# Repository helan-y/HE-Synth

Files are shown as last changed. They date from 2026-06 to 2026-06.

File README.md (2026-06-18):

# HE Synth

## About
A custom, compact, modular velocity-sensitive digital synthesizer, made with Hall-Effect keyswitches and DaisySeed. 

## Idea
I want to make music and I do not have money but I do have blood, sweat, and many, many tears. This is also a proof of concept towards bigger projects I want to make in the future!
- MIDI keyboard with trackballs for keys! like a roli seaboard but weird and isomorphic! what if piano could vibrato!!
- bigger modular midi (repeating pcb boards in series one for each octave) keyboard with keycaps like piano keys!
- sampler! vocoder! etc!

## Features
Hardware features:
- Velocity-sensitive! Aftertouch! Two/three/more octaves!
- Fully **modular**. Add more octaves, swap out MIDI controllers, swap out the synthesizer. Assembled with separate custom PCB boards for maximum customizability. 
- In-build audio! 3.5 mm headphone jack or speaker. 

Constantly updating firmware:
- Different presets! Different sound envelopes!
- There's even a looper!
- And a display!

## PCB
The PCB design is divided into four parts:
1. Main Board
2. Power Distribution Board (PDB)
3. Octave PCBs
    - 12 Hall-Effect Keyswitches
    - STM32 MCU Chip
    - UART data transmission
4. MIDI-Out PCB
    - ESP32
    - MIDI OUT
    - USB-C

### Main Board
- Contains the Daisy Seed
- Switches, rotary encoders, and potentiometers
- Display with microSD card
- Ports!
    - MIDI IN
    - AUDIO IN x2
    - AUDIO OUT x2
    - 3.5mm Headphone Jack
    - microUSB for programming the Daisy
    - USB-C for data

### PDB
- USB-C charging
- Battery management
- 6000 mAh Li-Po
- Boost to 5V
- Buck-Boost to 3V3

### Octave PCB
An octave of velocity-sensitive keys. Hall-effect sensors, processed into usable data for the Daisy Seed. 
- 12 Hall-Effect Keyswitches
- STM32 MCU Chip
- UART data transmission

### MIDI-Out PCB
- ESP32
- MIDI OUT
- USB-C

## CAD

## Firmware
Firmware coded with C++ and libraries libDaisy and daisySP. 

## BOM
### Main PCB
- 1x Electro-Smith Daisy Seed
- 2x EC11 Rotary Encoders
- 6x Cherry MX Keyswitches
- 9x Potentiometers
- 1x 3-pin Male Header JST-PH
- 1x 10-pin JST
- 1x 4-pin Male Header JST-PH
- 2x DIN-5 MIDI Jack
- 1x 3.5mm Headphone Jack
- 2x PJ-320 Jacks
- 1x Optocoupler
- 1x Speaker

### Octave PCB 
- 12x Gateron Jade Magnetic Switches
- 12x Linear Hall-Effect Sensors
- 1x STM32
- 12x 0.1uF Capacitors
- 1x 2-Pin Male Header JST-PH 
- 1x 4-Pin Male Header JST-PH
- 1x RS-485
- 1x 3-Bit DIP Switch

Three of these for this particular iteration!

### Power Distribution Board
- 1x USB-C Receptacle
- 3x 2-Pin Male Header JST-PH
- 1x 3-Pin Male Header JST-PH
-

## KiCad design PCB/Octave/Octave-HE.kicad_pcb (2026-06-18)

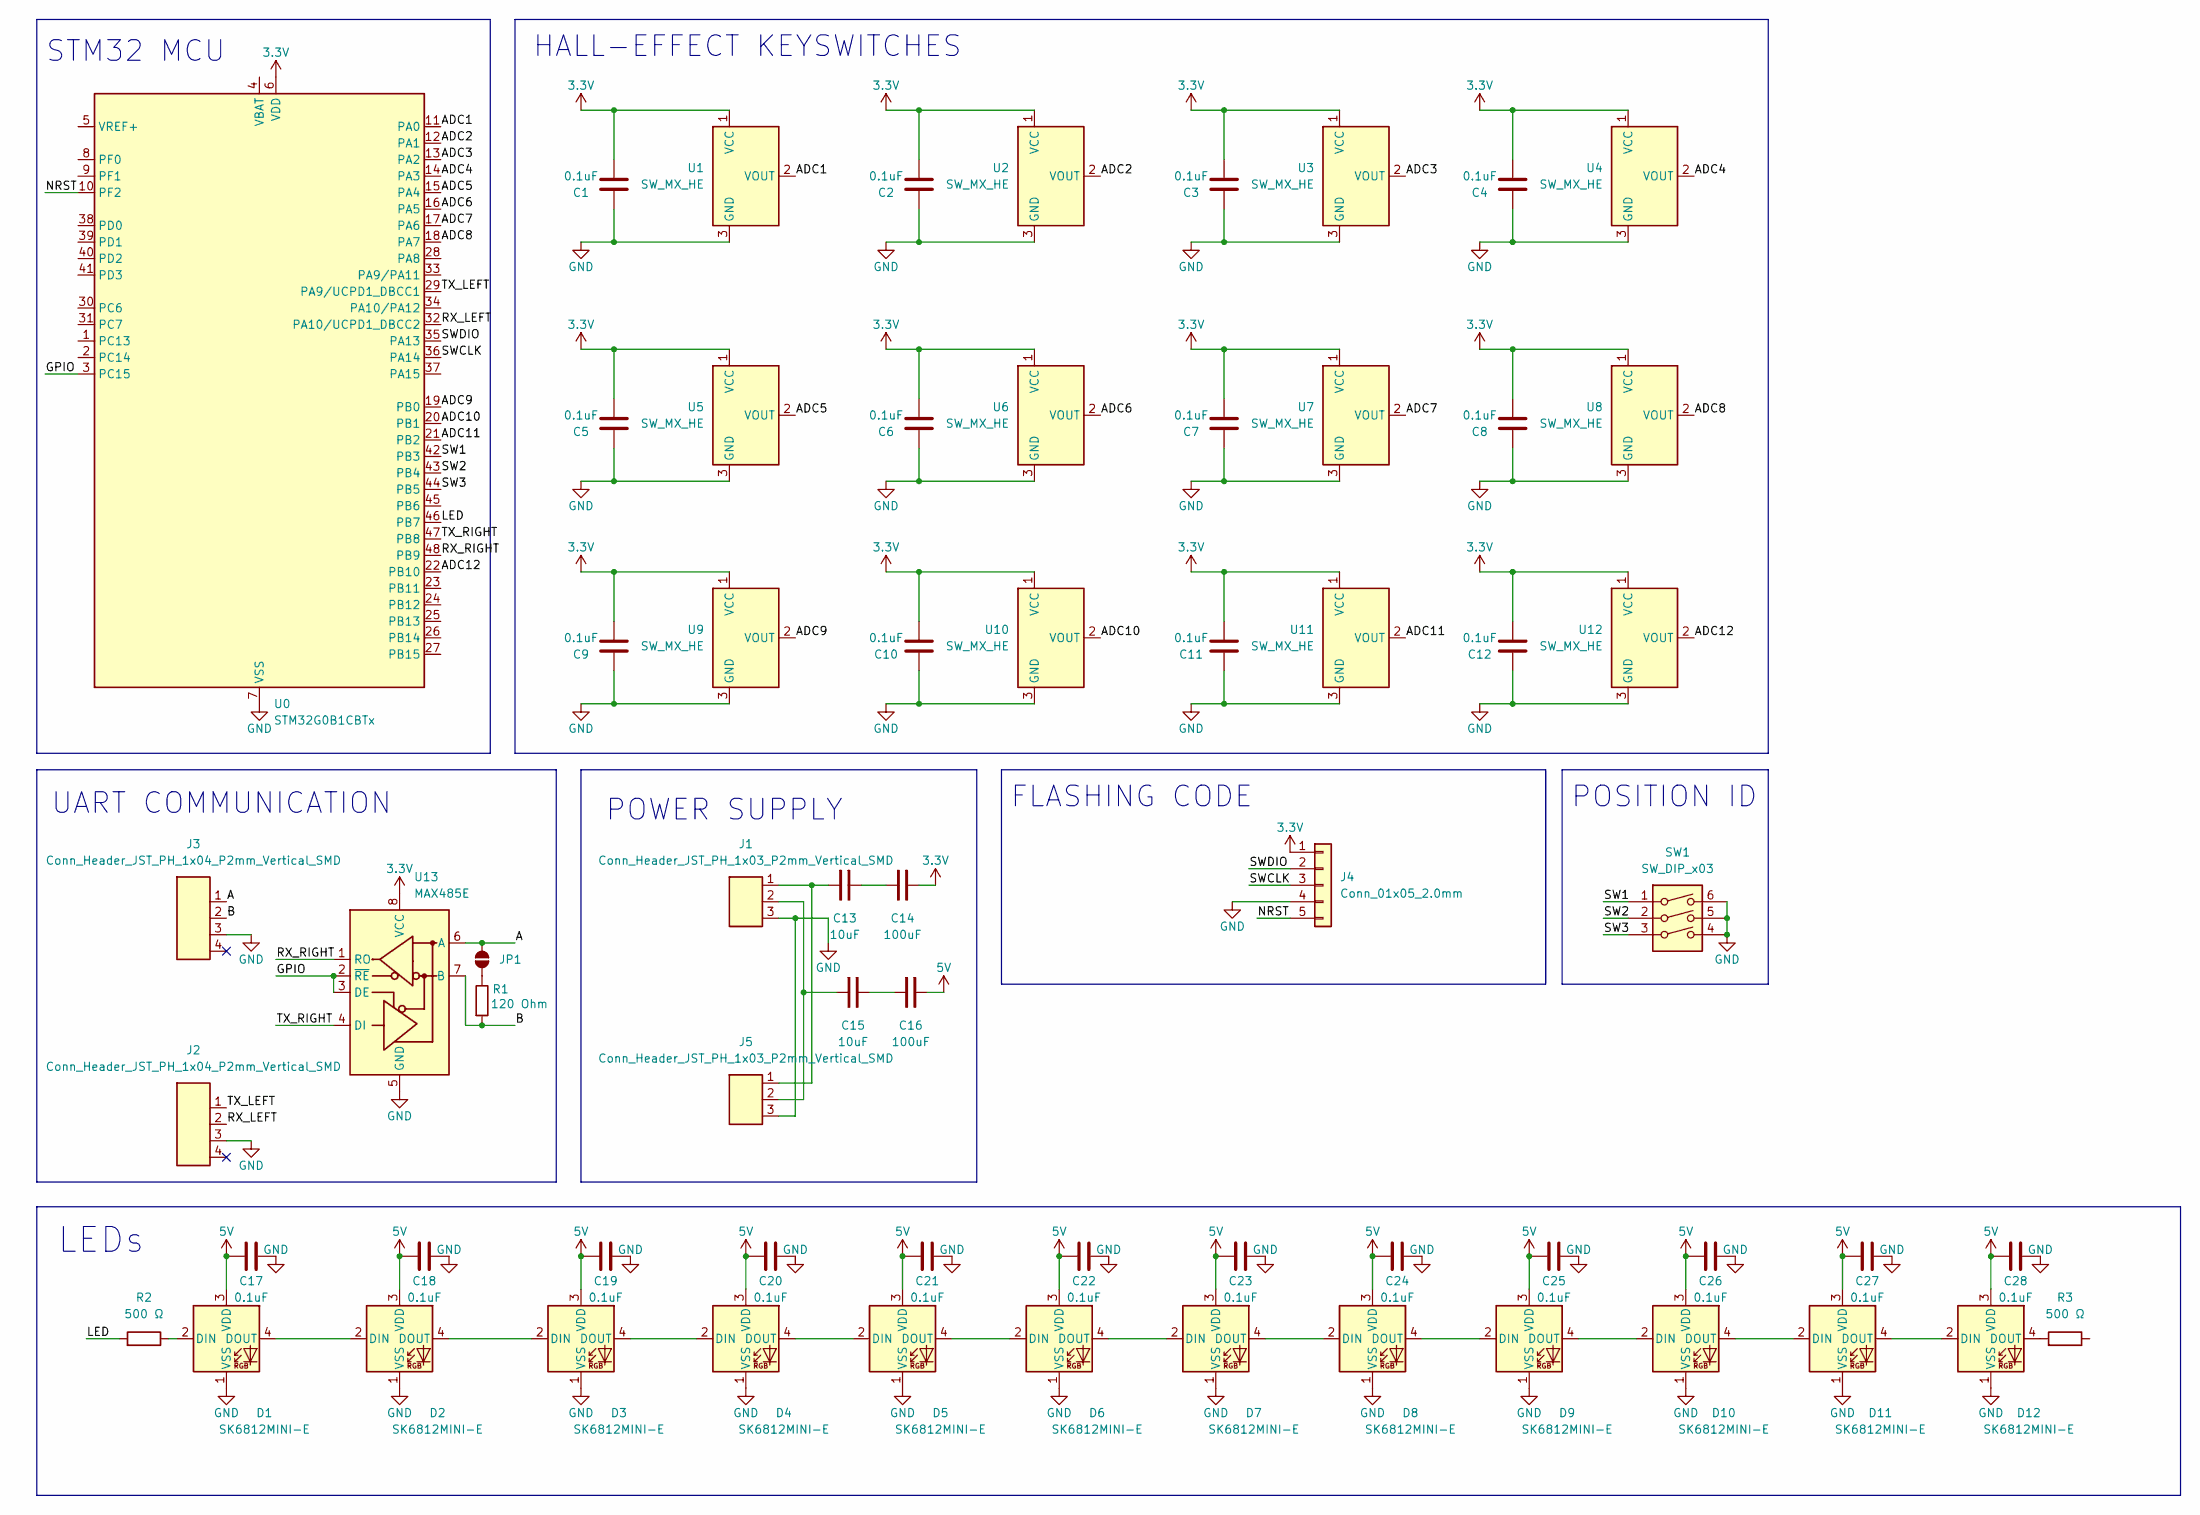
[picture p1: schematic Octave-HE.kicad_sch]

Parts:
C1, C2, C3, C4, C5, C6, C7, C8, C9, C10, C11, C12, C17, C18, C19, C20, C21, C22, C23, C24, C25, C26, C27, C28: 0.1uF; C_0201_0603Metric_Clearance
C13, C15: 10uF; CP_EIA-3216-10_Kemet-I_HandSolder
C14, C16: 100uF; CP_EIA-3216-10_Kemet-I_HandSolder
D1, D2, D3, D4, D5, D6, D7, D8, D9, D10, D11, D12: SK6812MINI-E; LED_SK6812MINI-E_3.2x2.8mm_P1.5mm_ReverseMount_clearance
J1, J5: Conn_Header_JST_PH_1x03_P2mm_Vertical_SMD; Header_JST_PH_1x03_P2mm_Vertical_SMD
J2, J3: Conn_Header_JST_PH_1x04_P2mm_Vertical_SMD; Header_JST_PH_1x04_P2mm_Vertical_SMD
J4: Conn_01x05_2.0mm; 1x05_P2.0mm_Socket_Vertical_SMD_Pin1RightDown
JP1: Jumper_2_NO
R1: 120 Ohm; R_0201_0603Metric
R2, R3: 500 Ω; R_0402_1005Metric
SW1: SW_DIP_x03; SW_DIP_SPSTx03_Slide_6.7x9.18mm_W6.73mm_P2.54mm_LowProfile_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
U0: STM32G0B1CBTx; LQFP-48_7x7mm_P0.5mm
U1, U2, U3, U4, U5, U6, U7, U8, U9, U10, U11, U12: SW_MX_HE; SW_MX_HE_0deg_1u
U13: MAX485E; SOIC-8_3.9x4.9mm_P1.27mm

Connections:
3.3V: C1.2, C2.2, C3.2, C4.2, C5.2, C6.2, C7.2, C8.2, C9.2, C10.2, C11.2, C12.2, C14.2, J4.1, U0.6 (VDD), U1.1 (VCC), U2.1 (VCC), U3.1 (VCC), U4.1 (VCC), U5.1 (VCC), U6.1 (VCC), U7.1 (VCC), U8.1 (VCC), U9.1 (VCC), U10.1 (VCC), U11.1 (VCC), U12.1 (VCC), U13.8 (VCC)
5V: C16.2, C17.2, C18.2, C19.2, C20.2, C21.2, C22.2, C23.2, C24.2, C25.2, C26.2, C27.2, C28.2, D1.3 (VDD), D2.3 (VDD), D3.3 (VDD), D4.3 (VDD), D5.3 (VDD), D6.3 (VDD), D7.3 (VDD), D8.3 (VDD), D9.3 (VDD), D10.3 (VDD), D11.3 (VDD), D12.3 (VDD)
/A: J3.1, JP1.2 (B), U13.6 (A)
/ADC1: U0.11 (PA0), U1.2 (VOUT)
/ADC2: U0.12 (PA1), U2.2 (VOUT)
/ADC3: U0.13 (PA2), U3.2 (VOUT)
/ADC4: U0.14 (PA3), U4.2 (VOUT)
/ADC5: U0.15 (PA4), U5.2 (VOUT)
/ADC6: U0.16 (PA5), U6.2 (VOUT)
/ADC7: U0.17 (PA6), U7.2 (VOUT)
/ADC8: U0.18 (PA7), U8.2 (VOUT)
/ADC9: U0.19 (PB0), U9.2 (VOUT)
/ADC10: U0.20 (PB1), U10.2 (VOUT)
/ADC11: U0.21 (PB2), U11.2 (VOUT)
/ADC12: U0.22 (PB10), U12.2 (VOUT)
/B: J3.2, R1.1, U13.7 (B)
/GPIO: U0.3 (PC15), U13.2 (~RE), U13.3 (DE)
/LED: R2.1, U0.46 (PB7)
/NRST: J4.5, U0.10 (PF2)
/RX_LEFT: J2.2, U0.32 (PA10/UCPD1_DBCC2)
/RX_RIGHT: U0.48 (PB9), U13.1 (RO)
/SW1: SW1.1, U0.42 (PB3)
/SW2: SW1.2, U0.43 (PB4)
/SW3: SW1.3, U0.44 (PB5)
/SWCLK: J4.3, U0.36 (PA14)
/SWDIO: J4.2, U0.35 (PA13)
/TX_LEFT: J2.1, U0.29 (PA9/UCPD1_DBCC1)
/TX_RIGHT: U0.47 (PB8), U13.4 (DI)
GND: C1.1, C2.1, C3.1, C4.1, C5.1, C6.1, C7.1, C8.1, C9.1, C10.1, C11.1, C12.1, C17.1, C18.1, C19.1, C20.1, C21.1, C22.1, C23.1, C24.1, C25.1, C26.1, C27.1, C28.1, D1.1 (VSS), D2.1 (VSS), D3.1 (VSS), D4.1 (VSS), D5.1 (VSS), D6.1 (VSS), D7.1 (VSS), D8.1 (VSS), D9.1 (VSS), D10.1 (VSS), D11.1 (VSS), D12.1 (VSS), J1.3, J2.3, J3.3, J4.4, J5.3, SW1.4, SW1.5, SW1.6, U0.7 (VSS), U1.3 (GND), U2.3 (GND), U3.3 (GND), U4.3 (GND), U5.3 (GND), U6.3 (GND), U7.3 (GND), U8.3 (GND), U9.3 (GND), U10.3 (GND), U11.3 (GND), U12.3 (GND), U13.5 (GND)
unnamed: C13.1, J1.1, J5.1
unnamed: C13.2, C14.1
unnamed: C15.1, J1.2, J5.2
unnamed: C15.2, C16.1
unnamed: D1.2 (DIN), R2.2
unnamed: D1.4 (DOUT), D2.2 (DIN)
unnamed: D2.4 (DOUT), D3.2 (DIN)
unnamed: D3.4 (DOUT), D4.2 (DIN)
unnamed: D4.4 (DOUT), D5.2 (DIN)
unnamed: D5.4 (DOUT), D6.2 (DIN)
unnamed: D6.4 (DOUT), D7.2 (DIN)
unnamed: D7.4 (DOUT), D8.2 (DIN)
unnamed: D8.4 (DOUT), D9.2 (DIN)
unnamed: D9.4 (DOUT), D10.2 (DIN)
unnamed: D10.4 (DOUT), D11.2 (DIN)
unnamed: D11.4 (DOUT), D12.2 (DIN)
unnamed: D12.4 (DOUT), R3.1
unnamed: JP1.1 (A), R1.2

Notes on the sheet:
HALL-EFFECT KEYSWITCHES
LEDs
POSITION ID
STM32 MCU
UART COMMUNICATION
FLASHING CODE
POWER SUPPLY

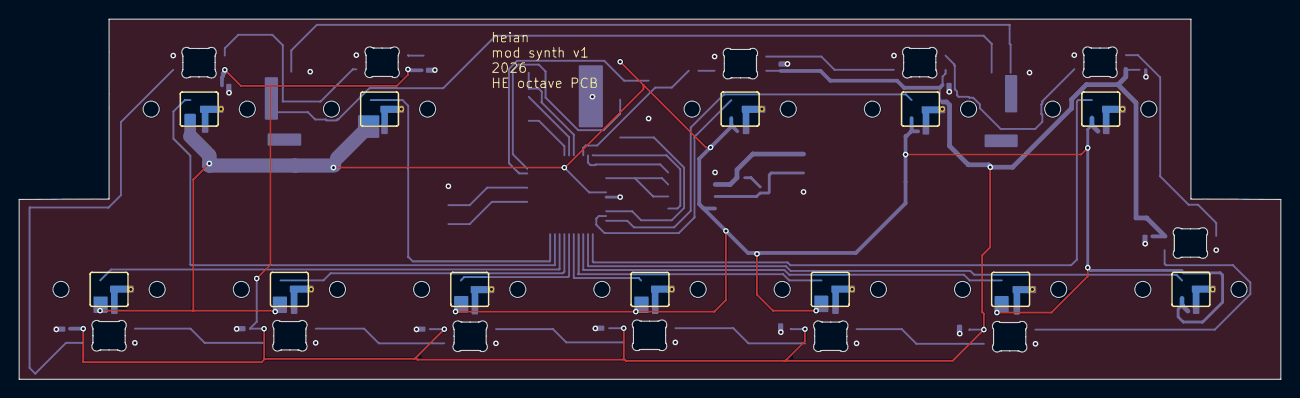
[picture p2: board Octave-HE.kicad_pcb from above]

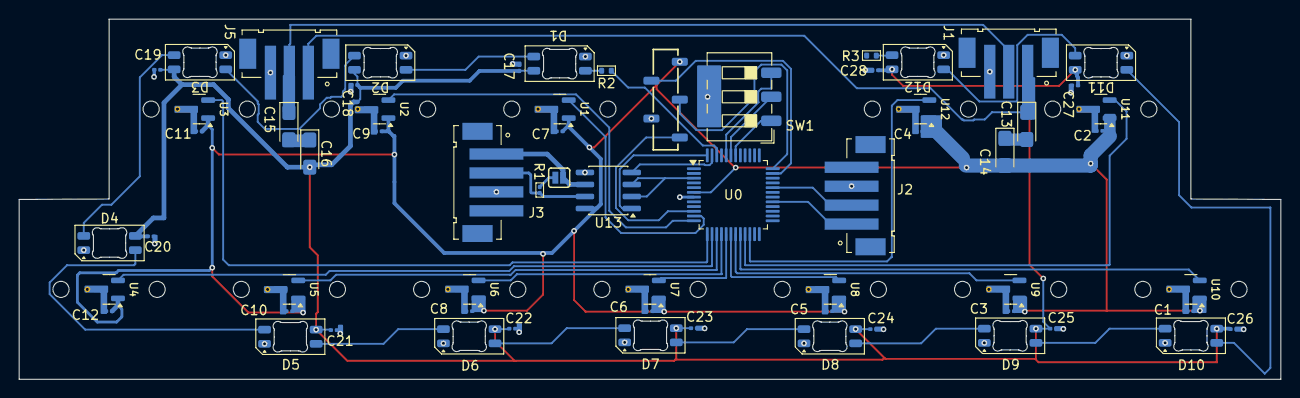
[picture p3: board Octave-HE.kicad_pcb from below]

Board: 2 copper layers, 133.3 x 38.0 mm, 64 parts (64 on the bottom side), 47 nets.

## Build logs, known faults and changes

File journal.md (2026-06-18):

# journal #1: research, planning & starting on the schematic

this is going to be so long because this is planning for the whole project. this has been bouncing around my brain for a while so uh here. 

i want a compact synth! i am mildly broke and synths are expensive! i am fully willing to invest blood, sweat, and tears!

So much time off-camera spent on research and hunting down parts. This was a shockingly massive undertaking. I really should have learned signals & systems before doing this. Or maybe taken apart an existing synth. Or maybe tried something smaller. Oh well!

features (hopefully):
- - Velocity-sensitive!
- Two/three/more octaves!
- In-build audio! 3.5 mm headphone jack or speaker. 
- Different presets! Different sound envelopes!
- There's even a looper!
- And a display!

Five main problems for the schematic:
- Not enough pins. 24 hall-effect keys all need ADC (analog to digital) pins. 6 rotary encoders. A display. Some pins also have specialized functions, so not all pins are interchangeable. 
- Different demands on power supply. Linear hall-effect sensors run on 3V3. Sound systems generally run on 5V. LiPo Batteries supply 3.7V - 4.2V. The daisy seed can supply 3V3 but I don't think it has enough to power all the systems that need it, and it definitely doesn't have 5V. 
- Enough power?? This might take a lot of power? 
- Hall-effect switches. Getting all of the specifications and all that jazz. Never worked with them before! Should be fun!
- Signal integrity & latency. This is probably my biggest concern. I don't care that much about polling rate, but I do need the synth to not have noticable lag. The solutions to "not enough pins" also tends to collide with this problem. And I need the data from the keys to be coherent by the time the daisy seed processes it. 

Tentative solutions:
- I first thought about using analog multiplexers, but those scan too slowly, and that would require the Daisy to process all Hall-Effect inputs, both which would probably introduce lag to the keyboard. 
- Second solution --> make it modular. This was a much better idea. 
    1. It's going to save a bit in cost! the main pcb board is probably going to be 4 layers just because I don't want to deal with muddled signals, but the keyboard PCBs don't have to be! You also have to order at least 5 PCBs in one batch so that works well with this.
    2. It's modular! You can add more octaves to the synth without having to rehaul the entire thing or design a new PCB!
    3. Saves on processing time! Probably reduces latency! Each octave board has an onboard MCU chip that processes sensor information and returns velocity. 
    4. Cleaner signals!

So the PCB design is going to be divided into three parts:
1. Main Board
    - Contains the Daisy Seed!
    - switches, rotary encoders, and potentiometers!
    - a display with microSD!
    - ports!
        - MIDI IN
        - MIDI OUT
        - AUDIO IN
        - AUDIO OUT
        - 3.5mm Headphone Jack
        - microUSB for programming the Daisy
2. Power Distribution Board (PDB)
    - USB-C charging
    - Battery management
    - Boost to 5V
    - Buck-Boost to 3V3
3. Octave PCBs
    - 12 Hall-Effect Keyswitches
    - STM32 MCU Chip
    - UART connected in series

for this session, i worked on assembling the main schematic and arranging the PCB. 

took shockingly long. finding a display and figuring out the pins? the one specific JST connectors where the pins were just a little off on the schematic, making it basically impossible to connect nets or wires?? finding all the 3d models?? i'm glad the planning is finally over though. this has been such a long project. 

i need to finish adding the ports and figuring out if i need a mux for all the inputs, but most the parts are here!!

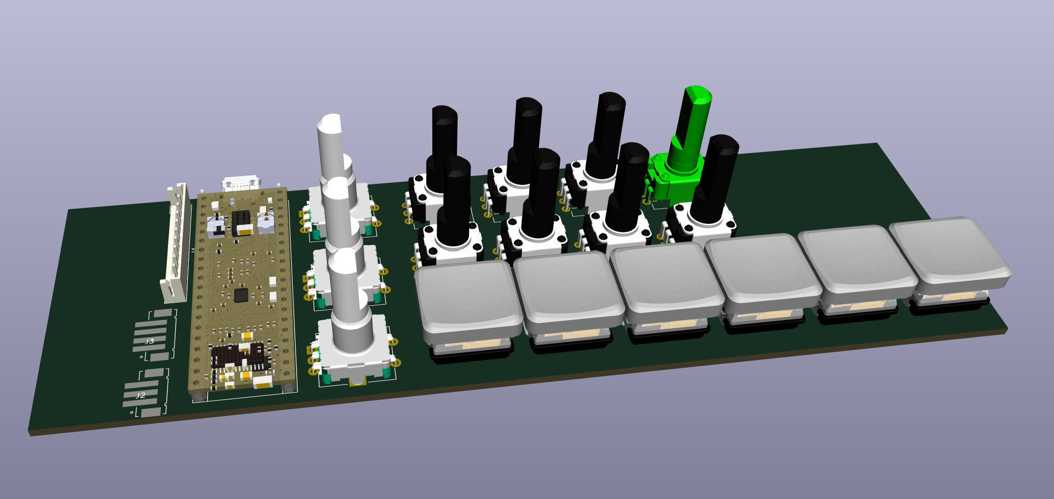
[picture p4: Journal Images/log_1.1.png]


# journal #2: octave PCB & research

so much research. my lord. 

so i'm planning for this synth to really be a modular midi keyboard + a daisy synthesizer. i should make one more PCB that's home to a microcontroller that processes the data from the octave PCBs and forwards it to the Main PCB (where the daisy is, or basically the synth). this way it's fully modular. if i want to swap out different midi keyboards or different synths i can quite easily. 

worked on the octave board! learned quite a lot about kicad and how to handle footprints and 3d models so hopefully my life should get easier later. found out i was editing specific footprints so the 3d models never saved :\( lesson learned !!

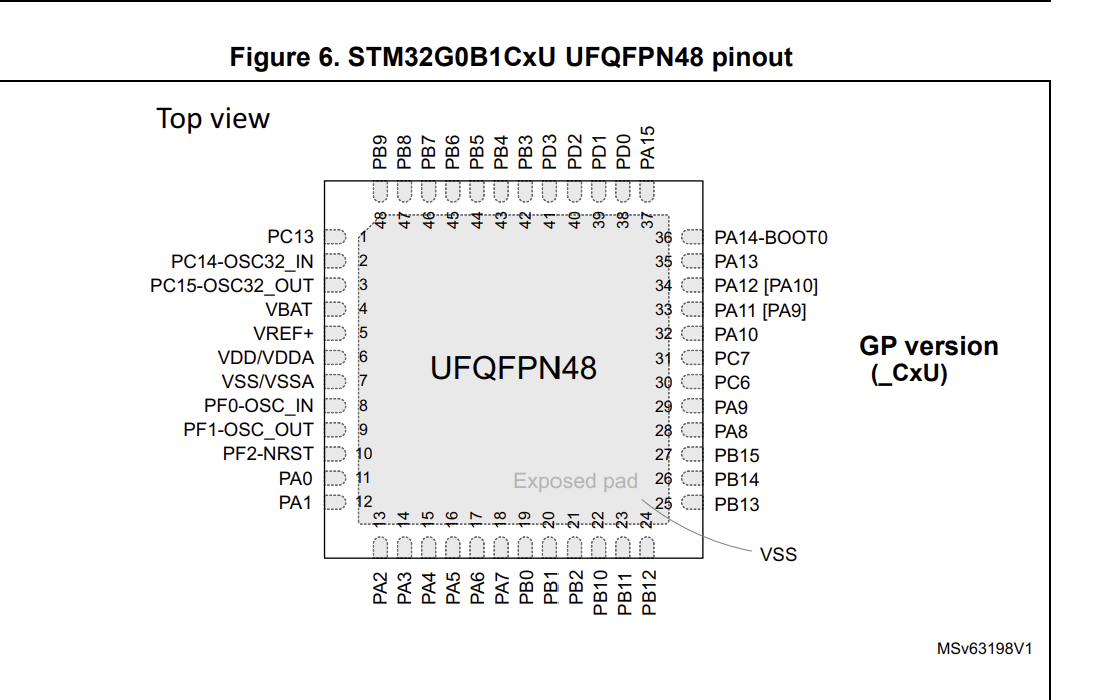
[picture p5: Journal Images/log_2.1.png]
)

have laid out the general schematic and pcb. i still need to figure out uart protocol and how to use the rs-485 to reduce interference. but that comes later

this was fairly simple ! at least this bit ! and i get a nice board to look at !

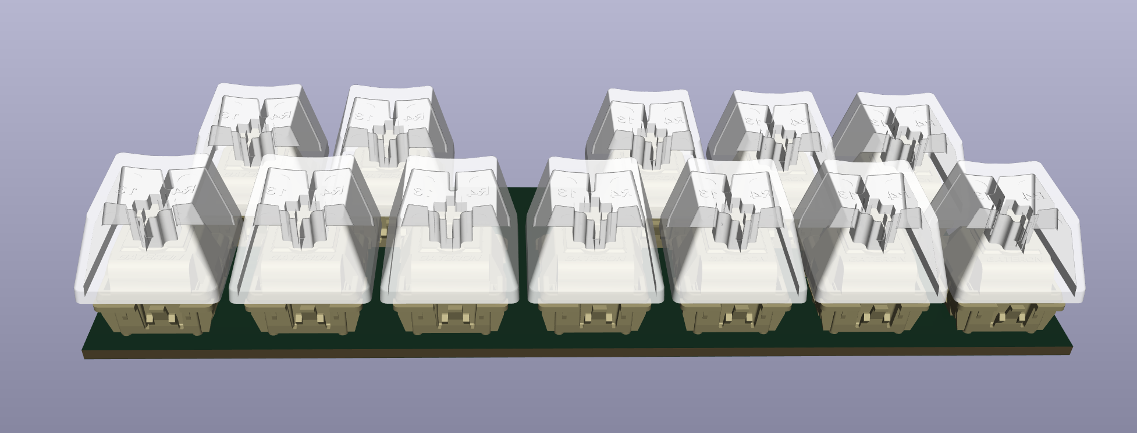
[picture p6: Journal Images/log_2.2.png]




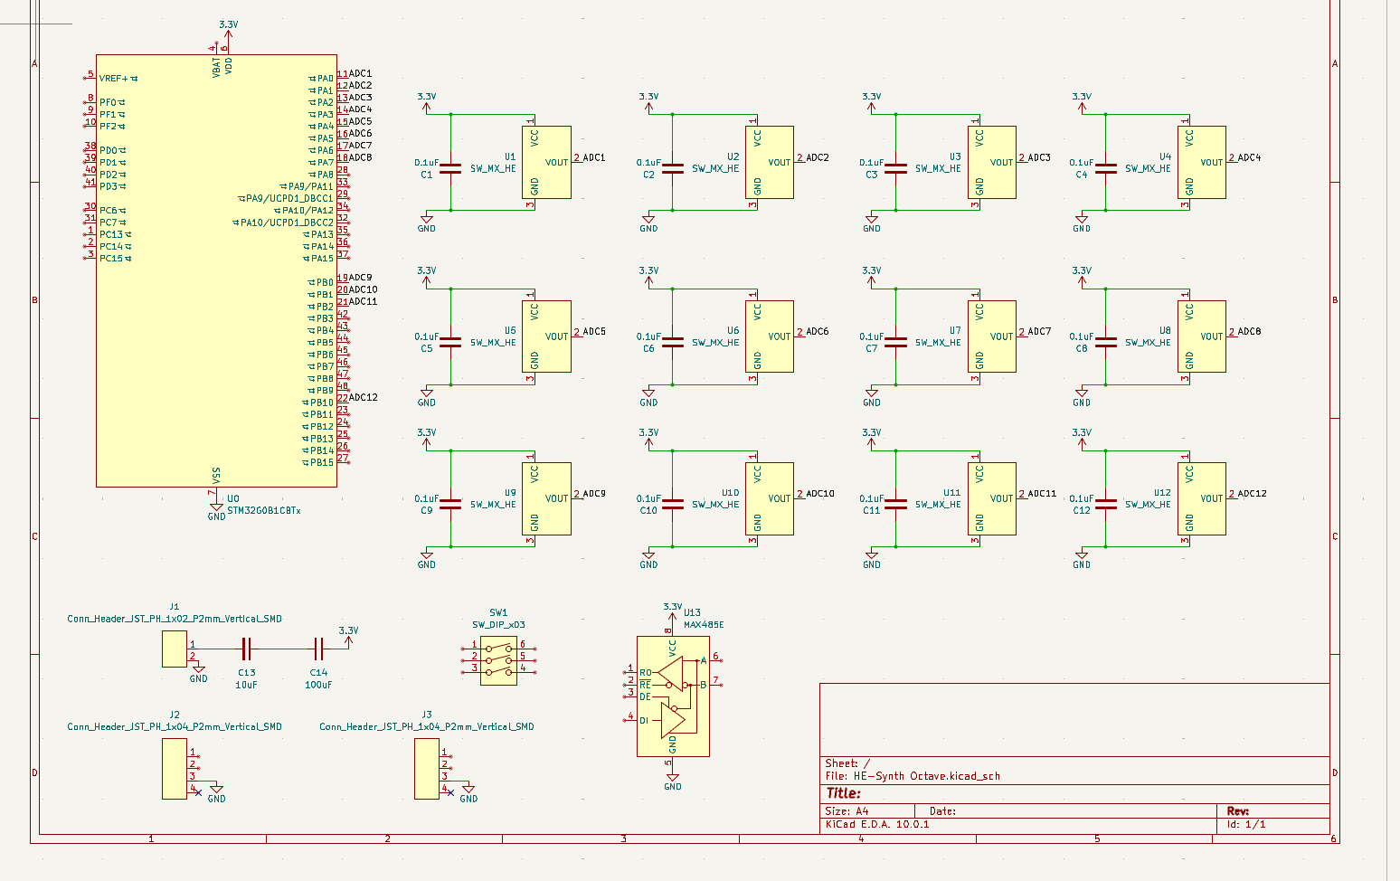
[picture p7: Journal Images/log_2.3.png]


# journal #3: octave PCB finished \(pain and suffering\) 

so this is unwireable. i either fix the schematic or swap the layout or this has to be a 4 layer board. four layer boards are so much more expensive.

i did not know that this would be the prelude to THREE HOURS of suffering. 

again engineering is the measure of how much you can tolerate small successive problems until you combust. 

## schematic

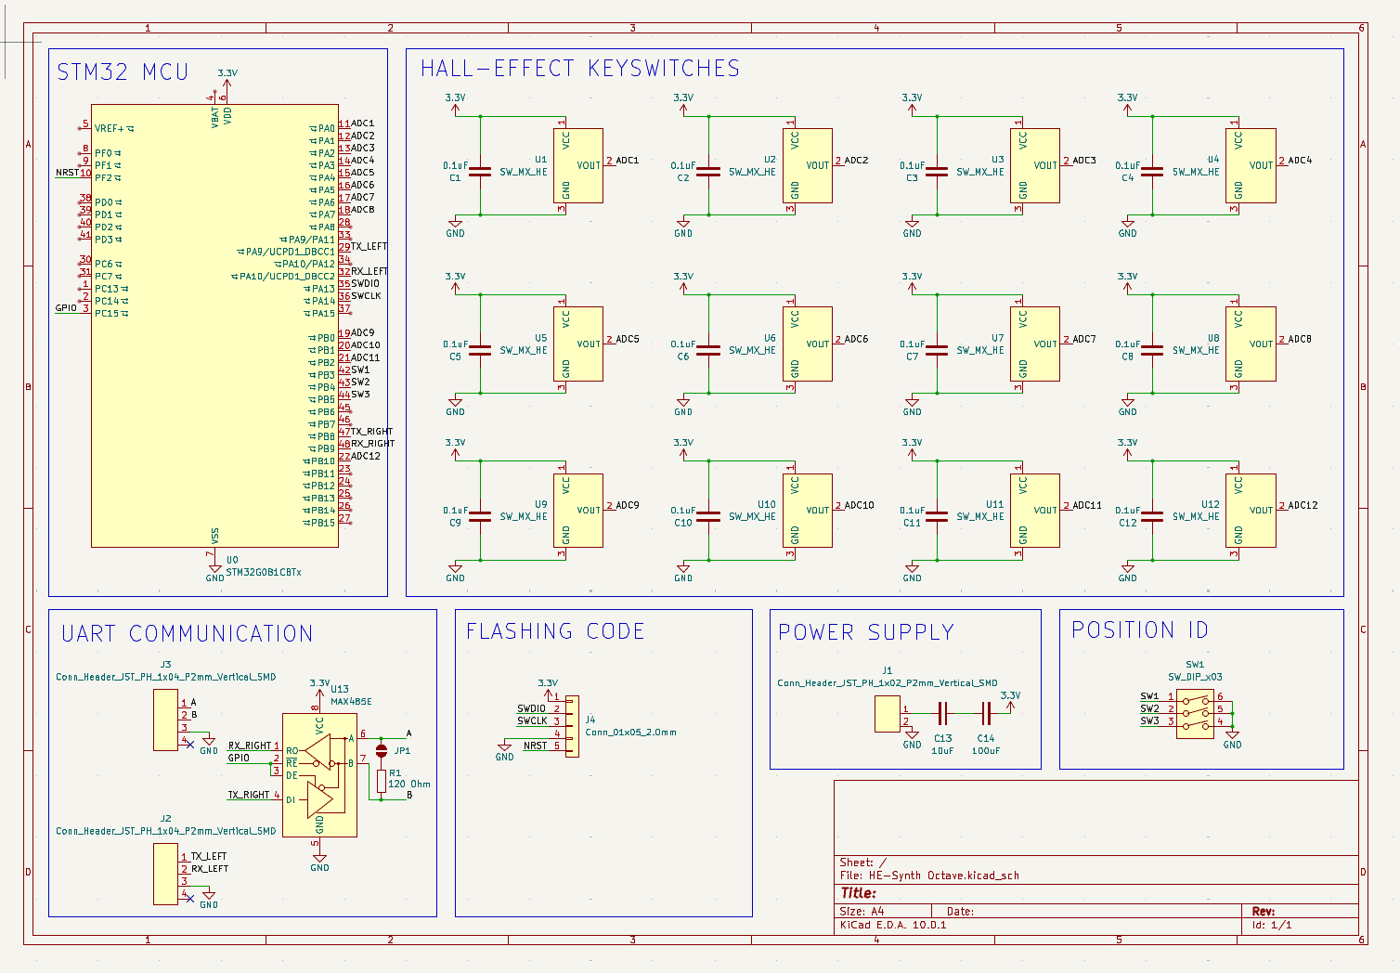
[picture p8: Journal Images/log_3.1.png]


this was mostly just staring at the datasheet and then the pcb to figure out which pins were available for which function, then which pin i COULD use that wouldn't ruin my life for wiring. this sounds so simple but it probably ate an hour just trying to figure out which configurations would work. thankfully i'm a bit more familiar with STM32 now, so future projects should go a little smoother.

## PCB

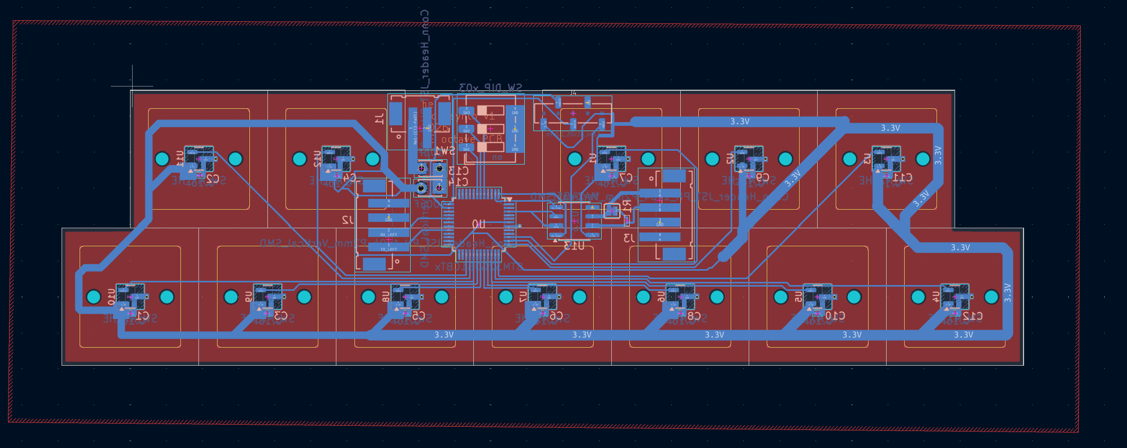
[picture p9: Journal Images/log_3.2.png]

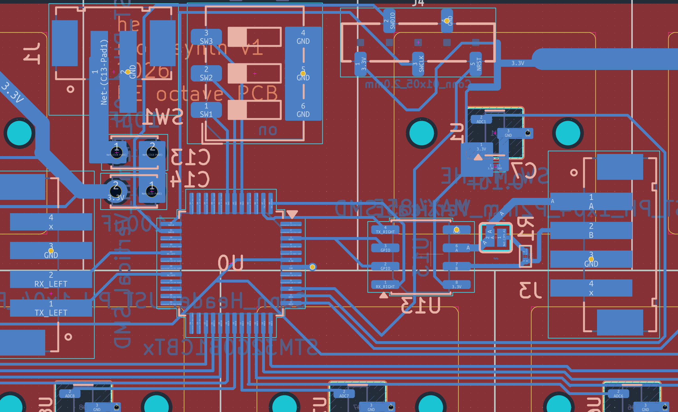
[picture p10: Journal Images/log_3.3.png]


wiring this was genuinely a nightmare. one layer is reserved for the GND plane for better signal processing, so no using two layers or vias to wire. i had to shuffle around so many of the keys just to be able to wire them to the correct adc pins. plus they can't interfere with the uart OR the power OR the firmware flashing port. had to move around so many part for this to function.

## PSB render

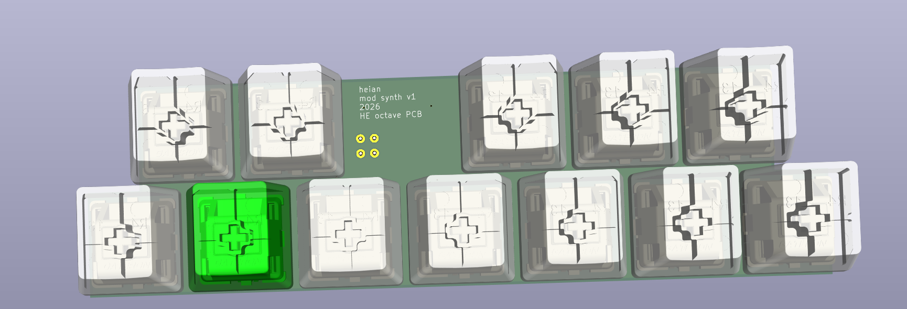
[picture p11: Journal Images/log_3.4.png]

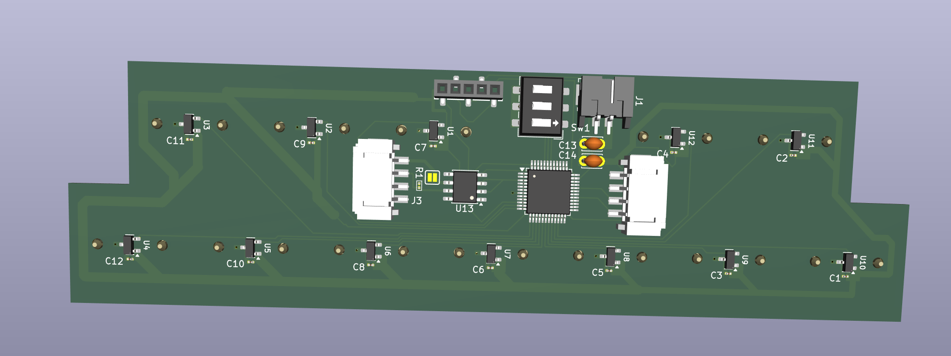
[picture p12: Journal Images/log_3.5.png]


I'M FREEEEE

# journal #4: laying out the main PCB

(extra hour for off lapse work) 

honestly a lot of just wrangling the layout and figuring out where the plugs are supposed to go?? and mapping out the regions of the pcb?? and then figuring out if it was fine??
- ports: i know i want at least a midi-in, a usb-c for independent power and data-output, and a few audio in and audio out ports. i also need to have a 3.5 mm headphone jack.
- these all need to be on the boundaries of the board. 
- i also have a 10-pin header for the display, but that needs to be close to the daisy, so i can shove a few ports and things "underneath" where the screen is going to be. i do need to get the dimensions of the thing but they are not listed.... it's 2.8 and 240x320, so i guess i just need to do pythagorean theorem ???? i'm not sure that's how it works. anyway this is a preliminary draft
- i also want this to be able to function as a standalone instrument (hence the usb port for alternative power) so the keys are in a vaguely octave formation. they don't have anything fancy though unfortunately. 

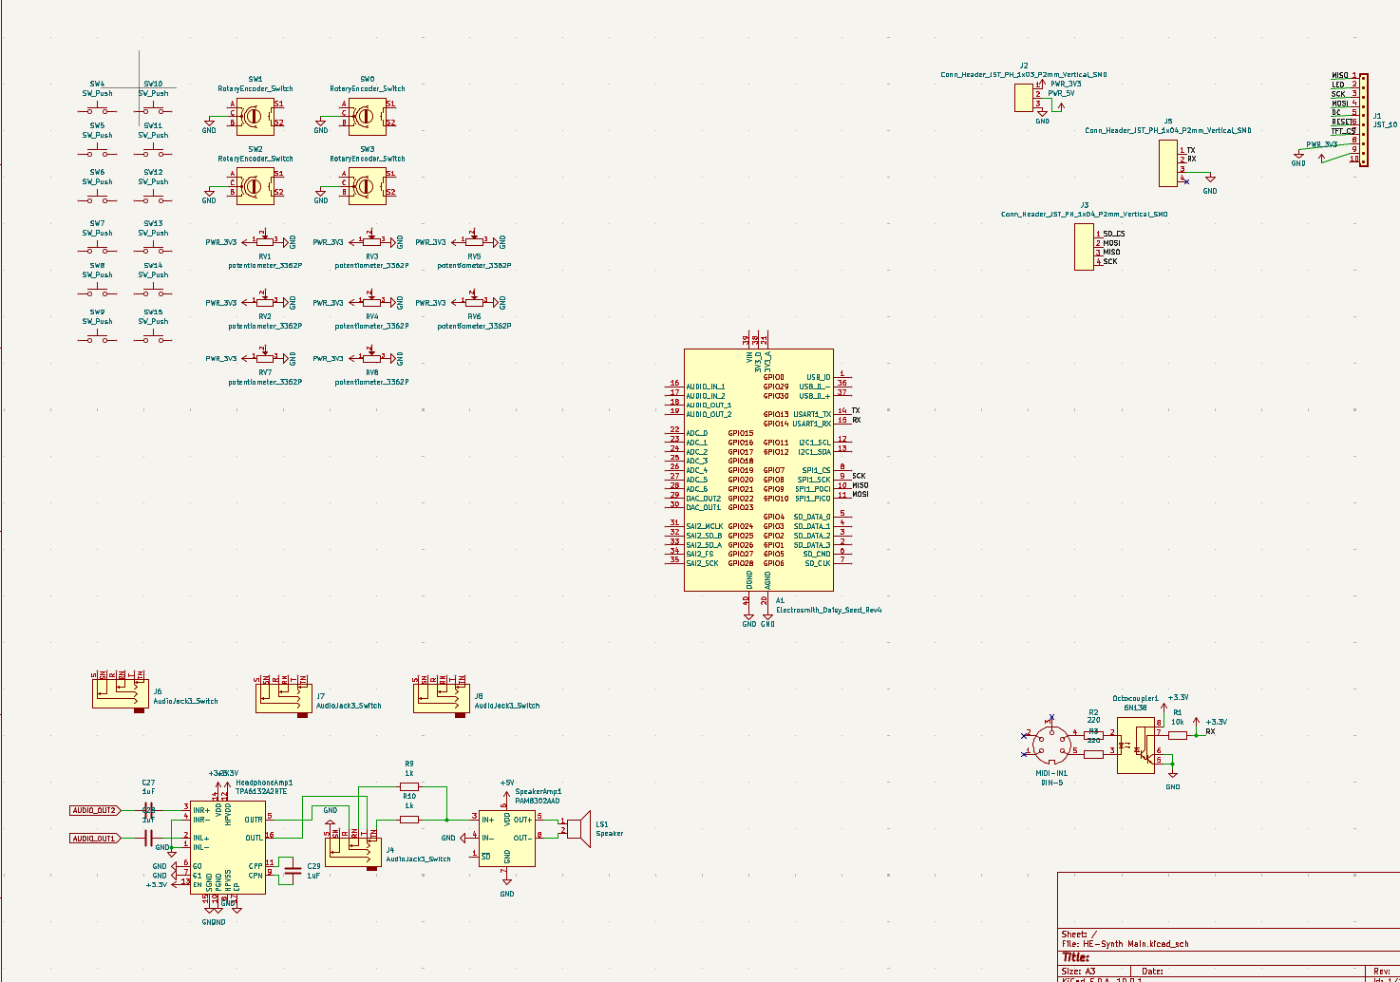
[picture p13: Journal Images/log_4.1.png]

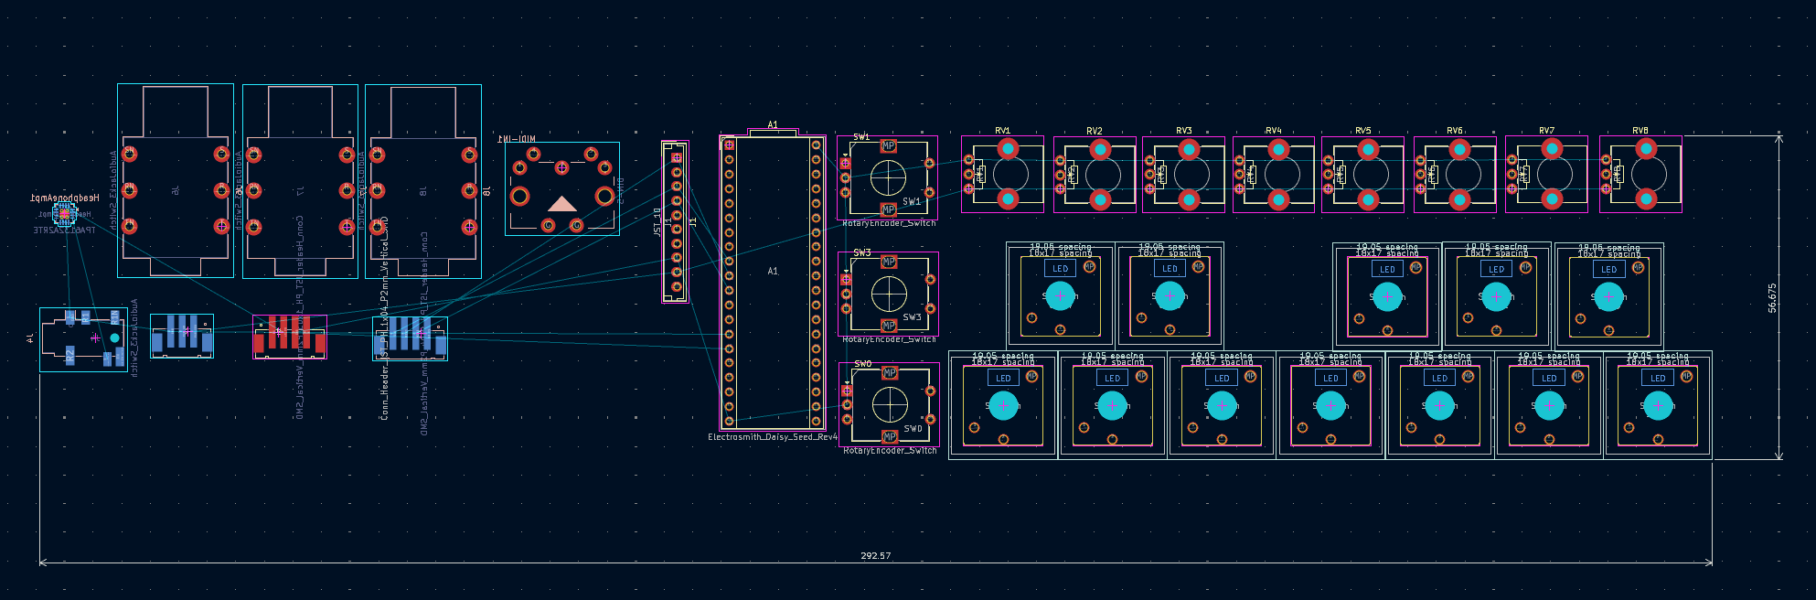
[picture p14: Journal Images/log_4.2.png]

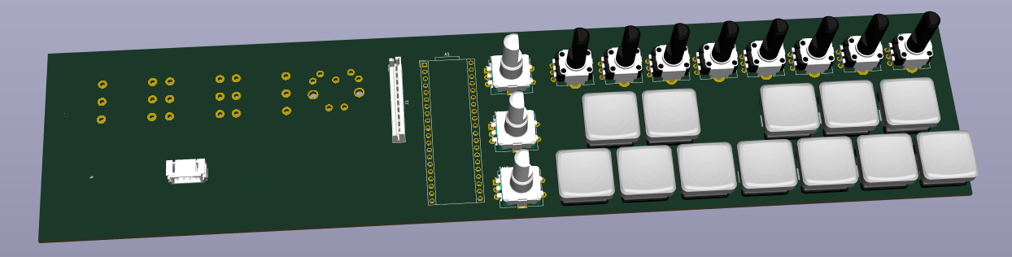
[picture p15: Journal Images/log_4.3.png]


# journal #5: off-screen research & planning

a few changes through the research and planning:
1. i don't want a separate power distribution board. i could probably fit that on the main PCB. plus the separate PDB would just be inconvenient. i thought it might introduce noise but it probably won't be an issue. 
2. i want there to be a separate midi processing board so that the chained octave boards bit can be separate. these should exist as **two separable halves**, the **hall-effect midi-controller** and the **daisy synth**. i also want to make separate cases for them ! that would be fun. the reason i'm not designing them separately is that the midi-controller bit transmits data through uart, and some of that would be lost if i converted it straight to midi. for example: the hall-effect sensor doesn't really track velocity. it tracks the position of a magnet in the switch above. so it can actually function as a slider, which would be really cool for things like volume, vibrato, and other effects. that would be lost if it went to midi. 
3. the separate midi processing board also needs to have a power section. luckily, it basically only uses 3V3, so i really only need a buck-boost to 3V3 or an LDO. 
4. i want there to be leds for the octave PCBs... i think i'm back for another world of suffering. but it would be so useful. highlighting notes that are in a scale? having a gradient of color for what position the sensor is currently detecting? it would genuinely be so worth it. 
5. so i'm due for another bout of pain and suffering. i genuinely think it might be worth it to make this a 4 layer board at this point
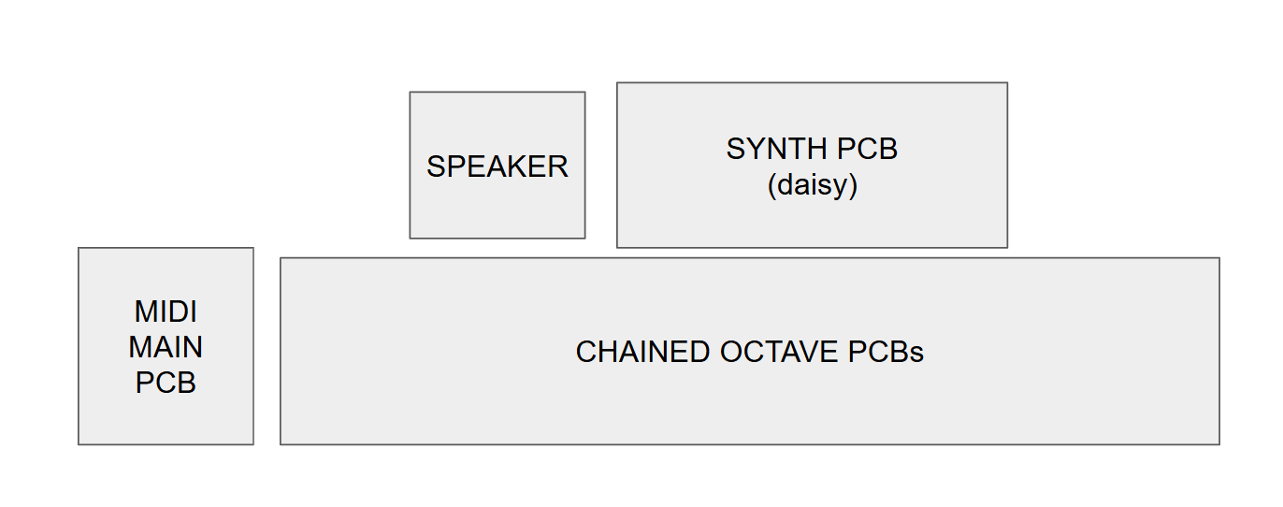
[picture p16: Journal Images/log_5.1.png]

this should be the general layout at this point, enclosed in one case

# journal #6: 
a revision to the earlier diagram:
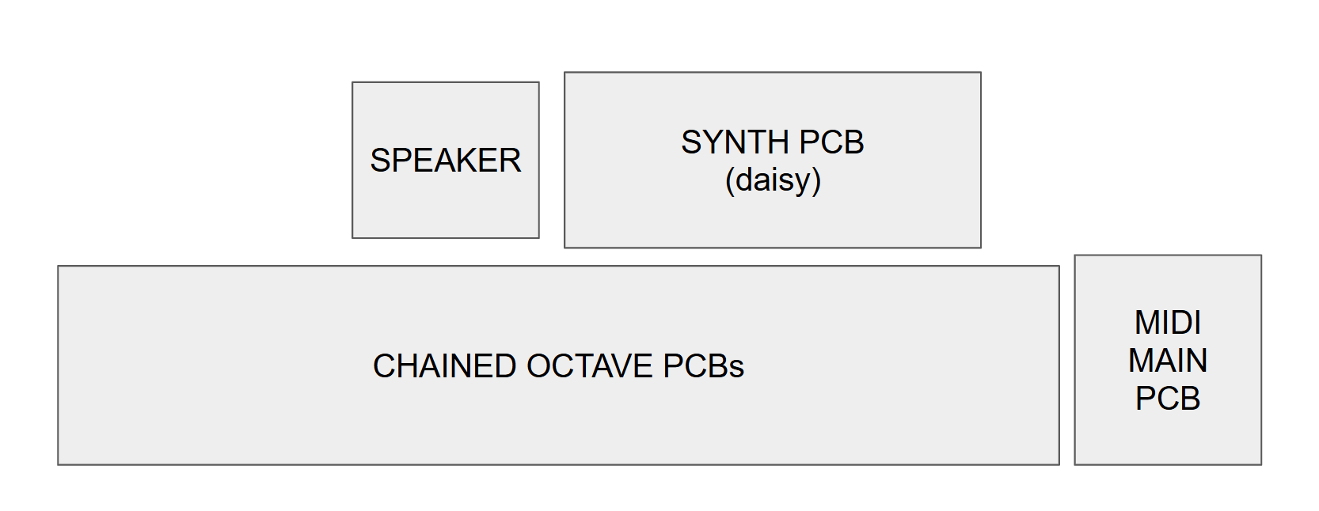
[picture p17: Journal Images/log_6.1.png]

the midi PCB should be on the right, as that's the direction the uart is supposed to flow. because of the side the rs-485 in on. 

so i decided to add leds to the octave pcbs. and also rc filtering. and i've also decided to give it two speakers and make it stereo. 

# jounal #7: main PCB schematic

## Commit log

2026-06-12 actual readme initial?
    [HE-synth.kicad_sch]
2026-06-13 read me schematic started
    [HE-synth.kicad_pcb, HE-synth.kicad_sch]
2026-06-13 read me schematic updates
2026-06-14 read me bom updates
2026-06-18 octave PCB done
    [Octave-HE-B_Cu.gbr, Octave-HE-B_Mask.gbr, Octave-HE-B_Paste.gbr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]
